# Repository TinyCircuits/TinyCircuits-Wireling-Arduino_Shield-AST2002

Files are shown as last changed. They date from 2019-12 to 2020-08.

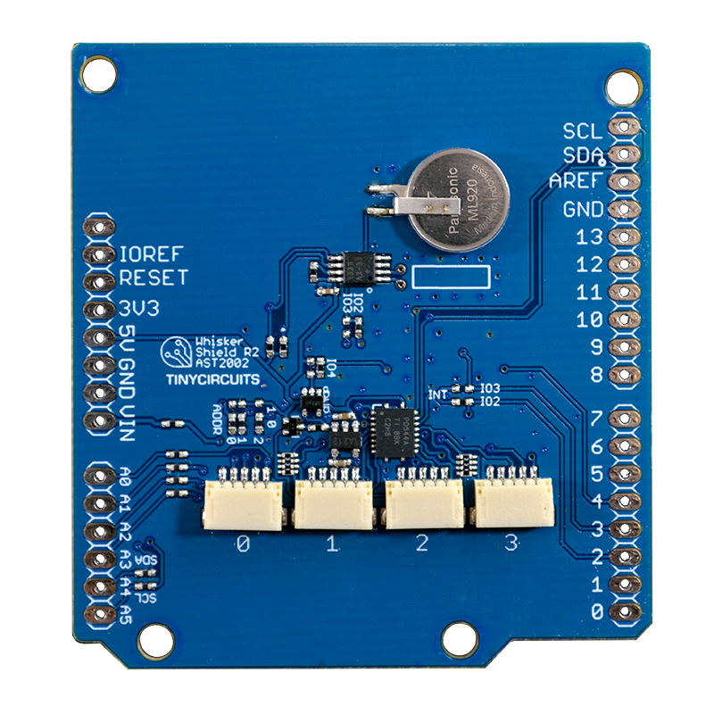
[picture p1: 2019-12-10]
images/AST2002-Tutorial-Image-01.png

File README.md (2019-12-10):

# TinyCircuits Wireling Arduino Shield AST2002
# AST2002 Rev2

The design files are located under design_files/ for the TinyCircuits AST2002 Rev 2 PCB. This is a Standard Arduino Shield that allows Standard Arduino users to connect up to 4 Wirelings to their Arduino projects.

Format is in Cadsoft Eagle format - Eagle version 6.2 was used for the original design.

For more infomation on this, check out the product page at TinyCircuits.com

# License:

Design by TinyCircuits.
All design files are released under the Creative Commons Attribution Share-Alike 3.0 License, see the following link for details: http://creativecommons.org/licenses/by-sa/3.0

All text above must be included in any redistribution or derived design

This project uses designs and concepts developed as part of the Arduino project and the LilyPad project.  The TinyCircuits design files themselves (schematics, PCB and libraries) are not directly derived from these works' design files and have been created new, however the concepts and basic architecture behind the TinyDuino and TinyLily products are derived and we thank the hard work of the organizations below for their contributions to open-source hardware:
  
Original Arduino Uno Design by Team Arduino

LilyPad Arduino Design by Leah Buechley and Sparkfun Electronics

Please support the open-source hardware community

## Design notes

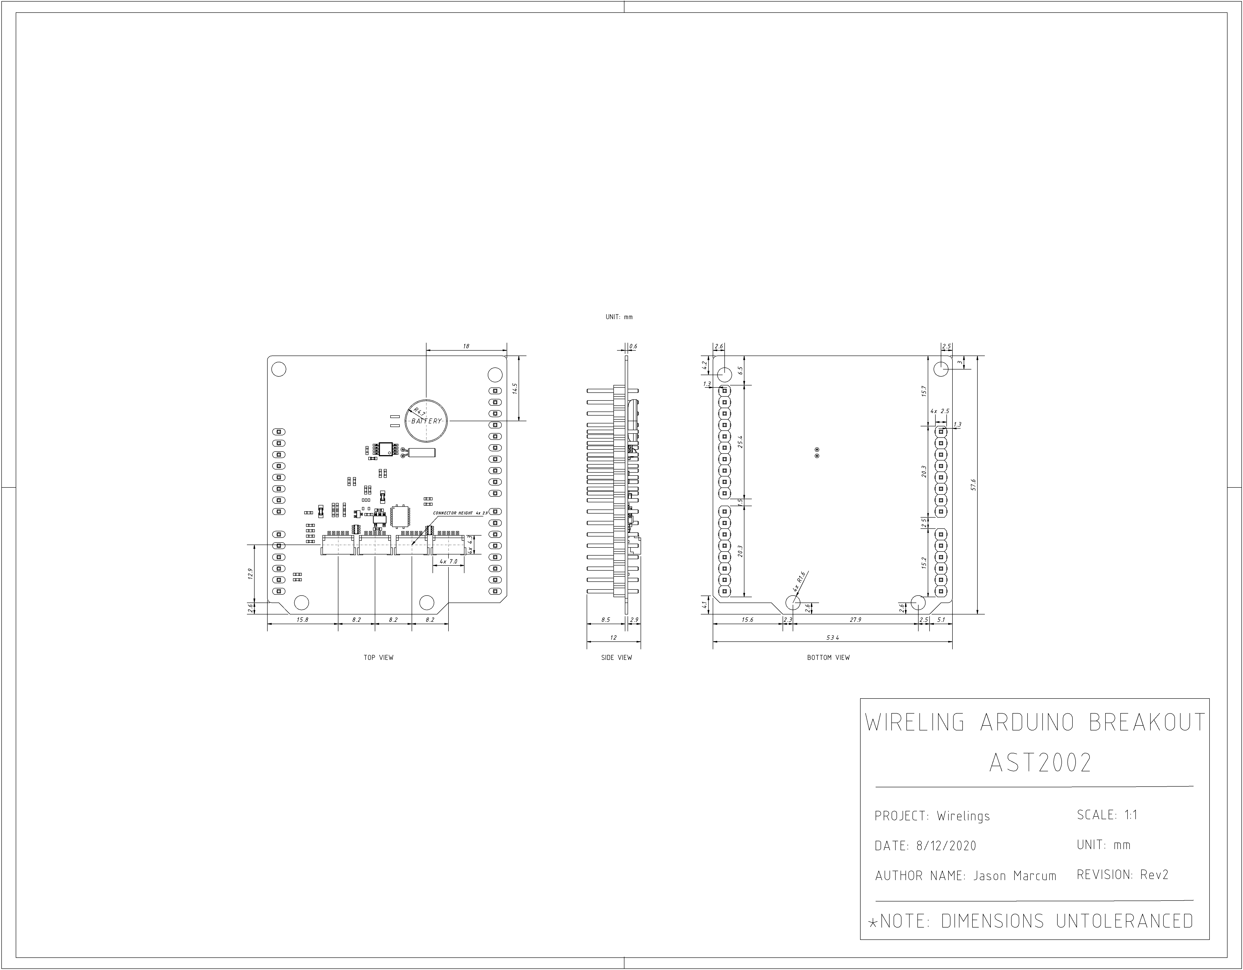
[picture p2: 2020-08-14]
cad/Wireling_ARDUINO_AST2002_REV2-DETAILED_DRAWING-PNG.png

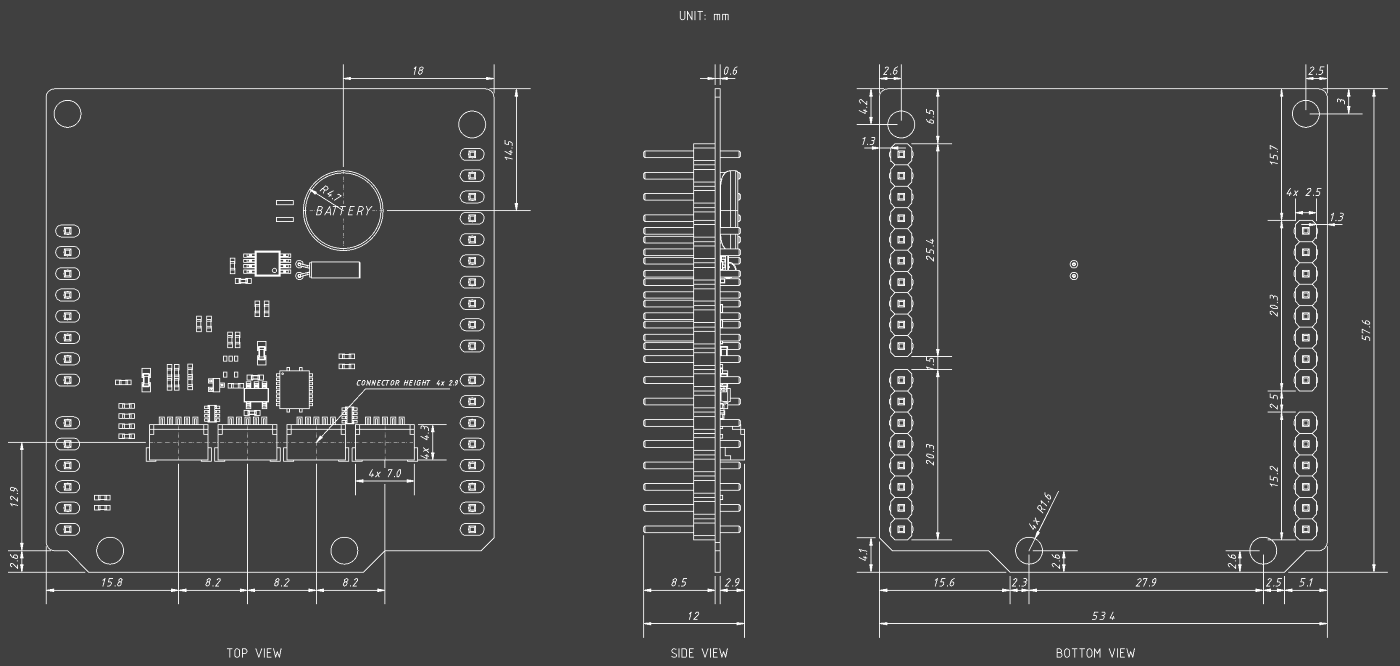
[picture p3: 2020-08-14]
cad/Wireling_ARDUINO_AST2002_REV2-DETAILED_DRAWING_COMPACT-PNG.png

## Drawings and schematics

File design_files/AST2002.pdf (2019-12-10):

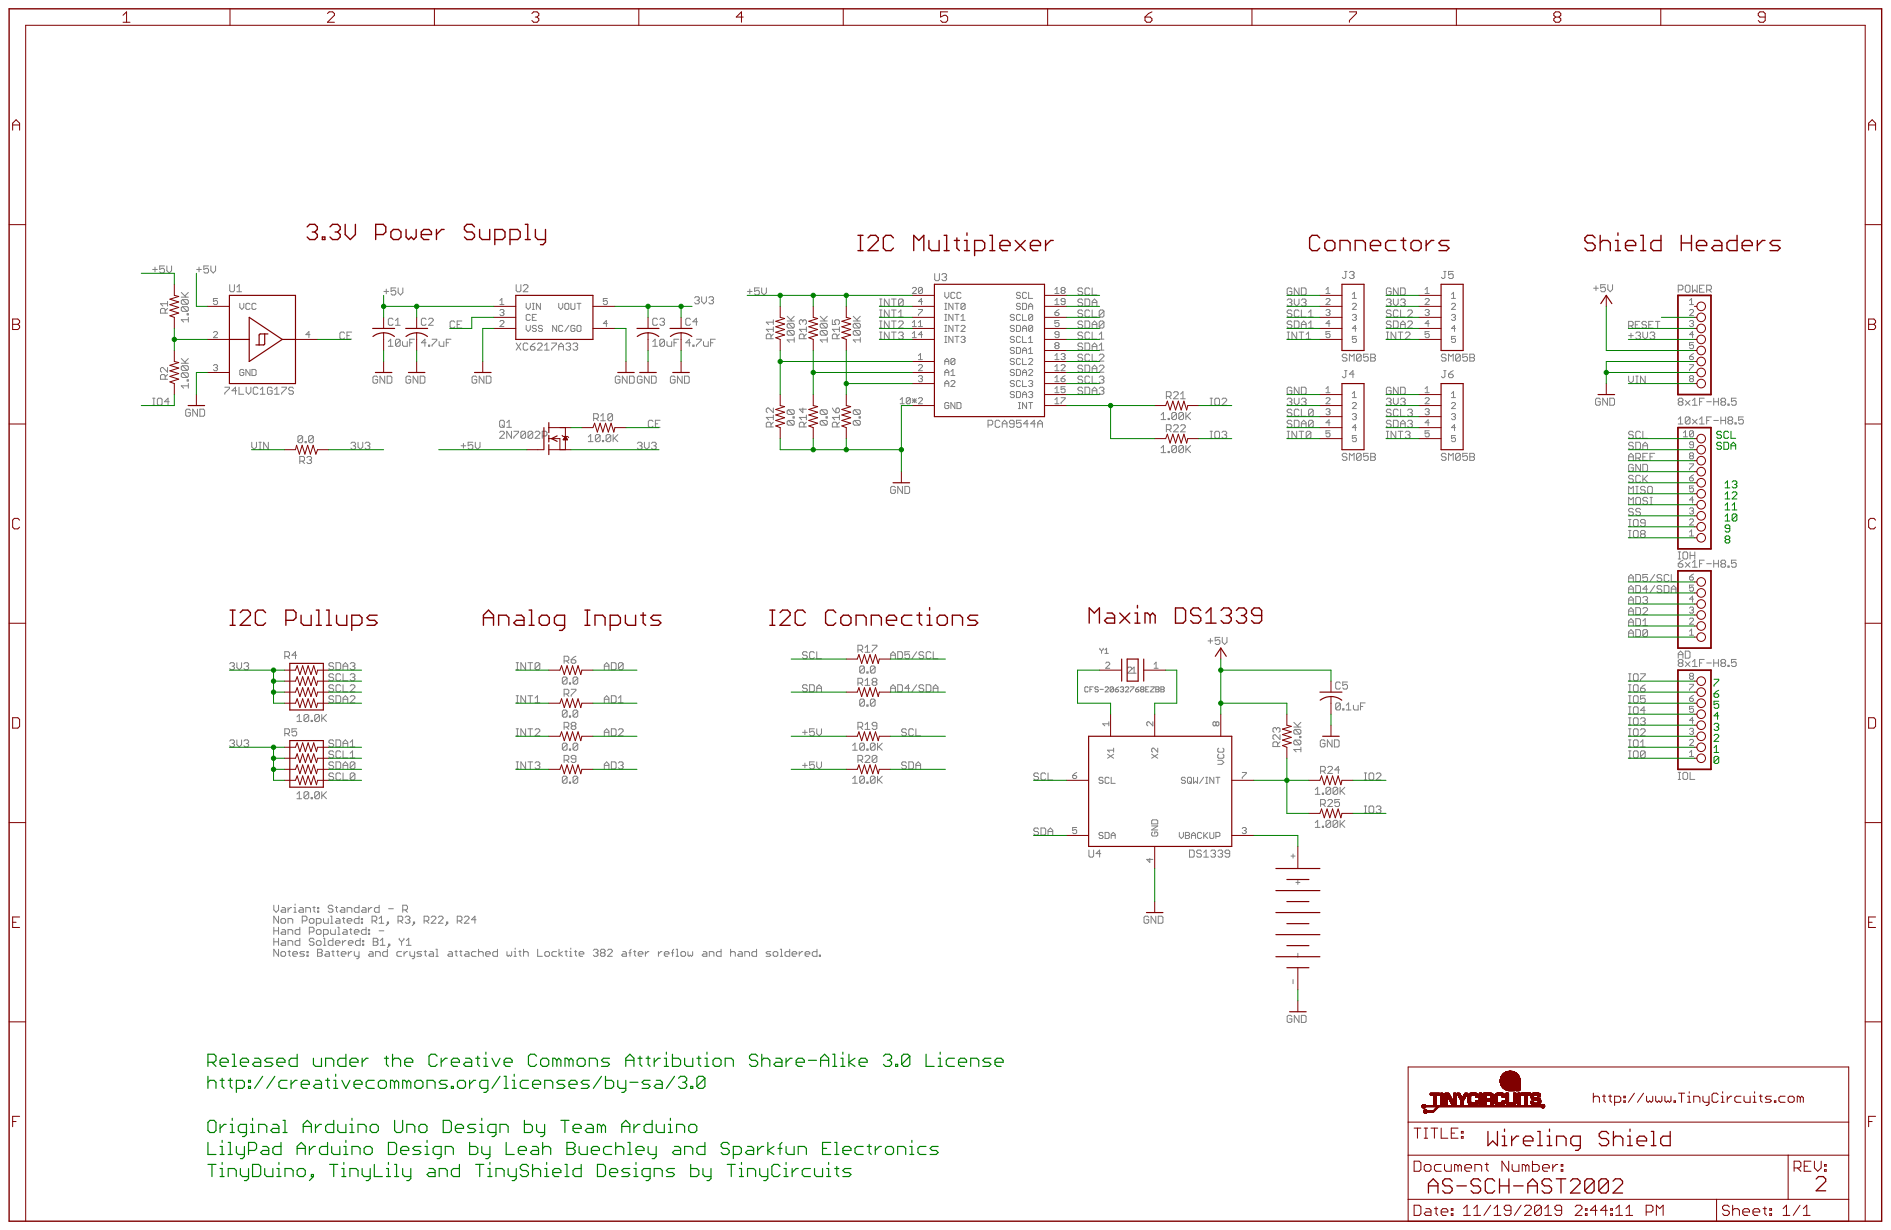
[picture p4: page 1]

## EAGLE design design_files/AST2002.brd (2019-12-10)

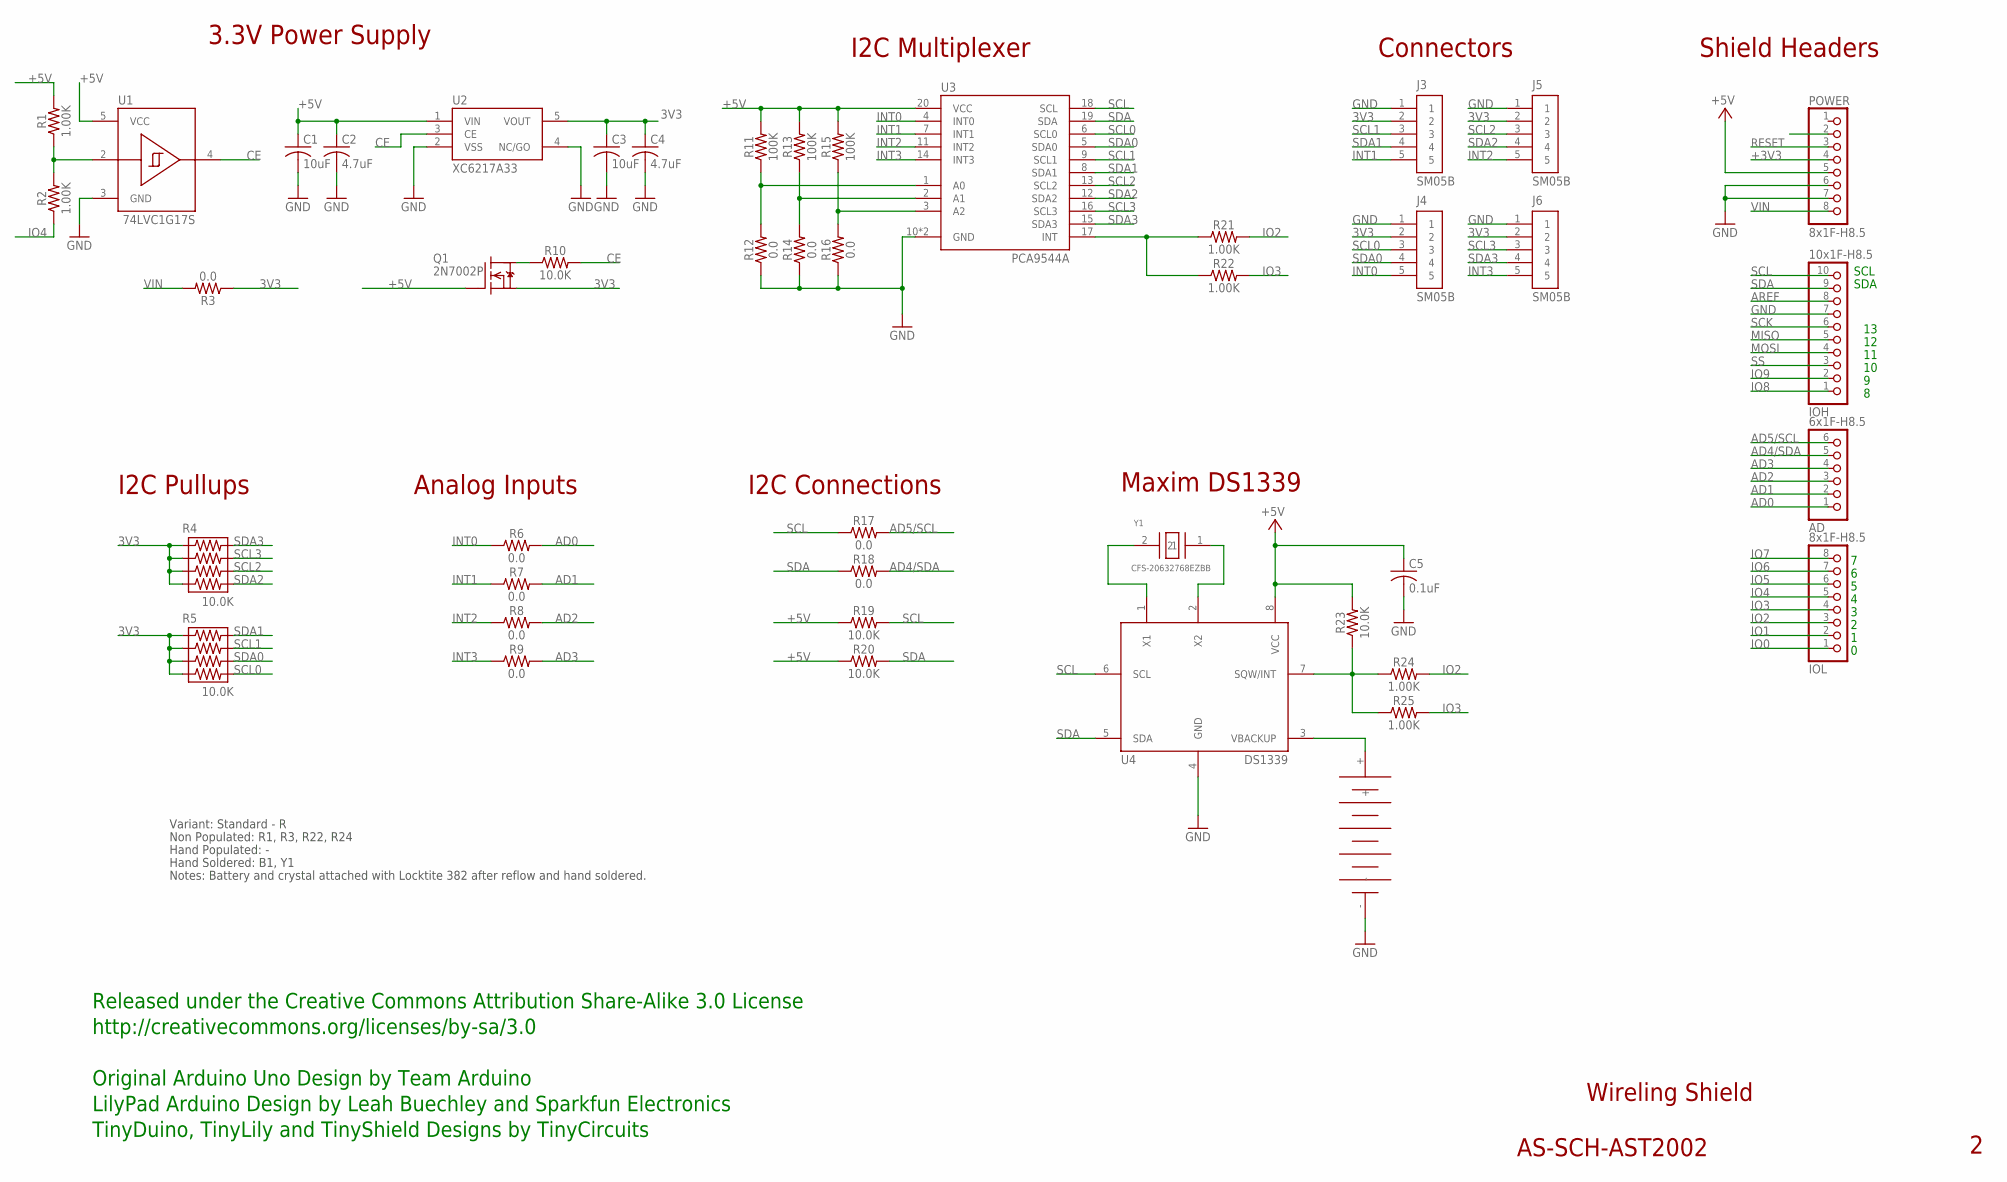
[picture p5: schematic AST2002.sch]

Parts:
AD: 6x1F-H8.5; 1X06
B1: ML-920S/DN
C1: 10uF; C0603; PARTNO AS-ITM-00002
C2, C4: 4.7uF; C0402; PARTNO AS-ITM-00242
C3: 10uF; C0603
C5: 0.1uF; C0402
IOH: 10x1F-H8.5; 1X10
IOL: 8x1F-H8.5; 1X08
J3, J4, J5, J6: SM05B; JST_SH_5X1
POWER: 8x1F-H8.5; 1X08
Q1: 2N7002P; SOT-416; PARTNO AS-ITM-00110
R1, R2, R24, R25: 1.00K; 0402; PARTNO AS-ITM-00003
R3, R12, R14, R16: 0.0; 0402; PARTNO AS-ITM-00076
R4, R5: 10.0K; 0402RPACK; PARTNO AS-ITM-00520
R6, R7, R8, R9, R17, R18: 0.0; 0402
R10, R23: 10.0K; 0402; PARTNO AS-ITM-00032
R11, R13, R15: 100K; 0402; PARTNO AS-ITM-00004
R19, R20: 10.0K; 0402
R21, R22: 1.00K; 0402
U1: 74LVC1G17S; SOT-353
U2: XC6217A33; SOT-25; PARTNO AS-ITM-00249
U3: PCA9544A; VQFN-20_4.5X3.5
U4: DS1339; 8-USOP
Y1: CFS-20632768EZBB; CRYSTAL_1.9MM_TH

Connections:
3V3: C3.1, C4.1, J3.2, J4.2, J5.2, J6.2, Q1.2 (S), R3.1, R4.1, R4.3, R4.5, R4.7, R5.1, R5.3, R5.5, R5.7, U2.5 (VOUT)
+3V3: POWER.4
+5V: C1.1, C2.1, C5.1, POWER.5, Q1.1 (G), R1.2, R11.2, R13.2, R15.2, R19.1, R20.1, R23.2, U1.5 (VCC), U2.1 (VIN), U3.20 (VCC), U4.8 (VCC)
AD0: AD.1, R6.2
AD1: AD.2, R7.2
AD2: AD.3, R8.2
AD3: AD.4, R9.2
AD4/SDA: AD.5, R18.2
AD5/SCL: AD.6, R17.2
AREF: IOH.8
CE: R10.2, U1.4 (Y), U2.3 (CE)
GND: B1.-, C1.2, C2.2, C3.2, C4.2, C5.2, IOH.7, J3.1, J4.1, J5.1, J6.1, POWER.6, POWER.7, R12.1, R14.1, R16.1, U1.3 (GND), U2.2 (VSS), U2.4 (NC/GO), U3.10 (GND), U3.PAD (GND), U4.4 (GND)
INT0: J4.5, R6.1, U3.4 (INT0)
INT1: J3.5, R7.1, U3.7 (INT1)
INT2: J5.5, R8.1, U3.11 (INT2)
INT3: J6.5, R9.1, U3.14 (INT3)
IO0: IOL.1
IO1: IOL.2
IO2: IOL.3, R21.2, R24.2
IO3: IOL.4, R22.2, R25.2
IO4: IOL.5, R2.1
IO5: IOL.6
IO6: IOL.7
IO7: IOL.8
IO8: IOH.1
IO9: IOH.2
MISO: IOH.5
MOSI: IOH.4
unnamed: Q1.3 (D), R10.1
unnamed: R11.1, R12.2, U3.1 (A0)
unnamed: R15.1, R16.2, U3.3 (A2)
unnamed: R21.1, R22.1, U3.17 (INT)
unnamed: R13.1, R14.2, U3.2 (A1)
unnamed: R23.1, R24.1, R25.1, U4.7 (SQW/INT)
unnamed: B1.+, U4.3 (VBACKUP)
unnamed: U4.1 (X1), Y1.2 (1)
unnamed: U4.2 (X2), Y1.1 (2)
unnamed: R1.1, R2.2, U1.2 (A)
RESET: POWER.3
SCK: IOH.6
SCL: IOH.10, R17.1, R19.2, U3.18 (SCL), U4.6 (SCL)
SCL0: J4.3, R5.8, U3.6 (SCL0)
SCL1: J3.3, R5.4, U3.9 (SCL1)
SCL2: J5.3, R4.6, U3.13 (SCL2)
SCL3: J6.3, R4.4, U3.16 (SCL3)
SDA: IOH.9, R18.1, R20.2, U3.19 (SDA), U4.5 (SDA)
SDA0: J4.4, R5.6, U3.5 (SDA0)
SDA1: J3.4, R5.2, U3.8 (SDA1)
SDA2: J5.4, R4.8, U3.12 (SDA2)
SDA3: J6.4, R4.2, U3.15 (SDA3)
SS: IOH.3
VIN: POWER.8, R3.2

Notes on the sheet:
Shield Headers
Wireling Shield
AS-SCH-AST2002
Released under the Creative Commons Attribution Share-Alike 3.0 License
http://creativecommons.org/licenses/by-sa/3.0
LilyPad Arduino Design by Leah Buechley and Sparkfun Electronics
TinyDuino, TinyLily and TinyShield Designs by TinyCircuits
Original Arduino Uno Design by Team Arduino
3.3V Power Supply
I2C Multiplexer
Connectors
Analog Inputs
I2C Pullups
Non Populated: R1, R3, R22, R24
Variant: Standard - R
SDA
SCL
Maxim DS1339
Hand Populated: -
Hand Soldered: B1, Y1
Notes: Battery and crystal attached with Locktite 382 after reflow and hand soldered.
I2C Connections

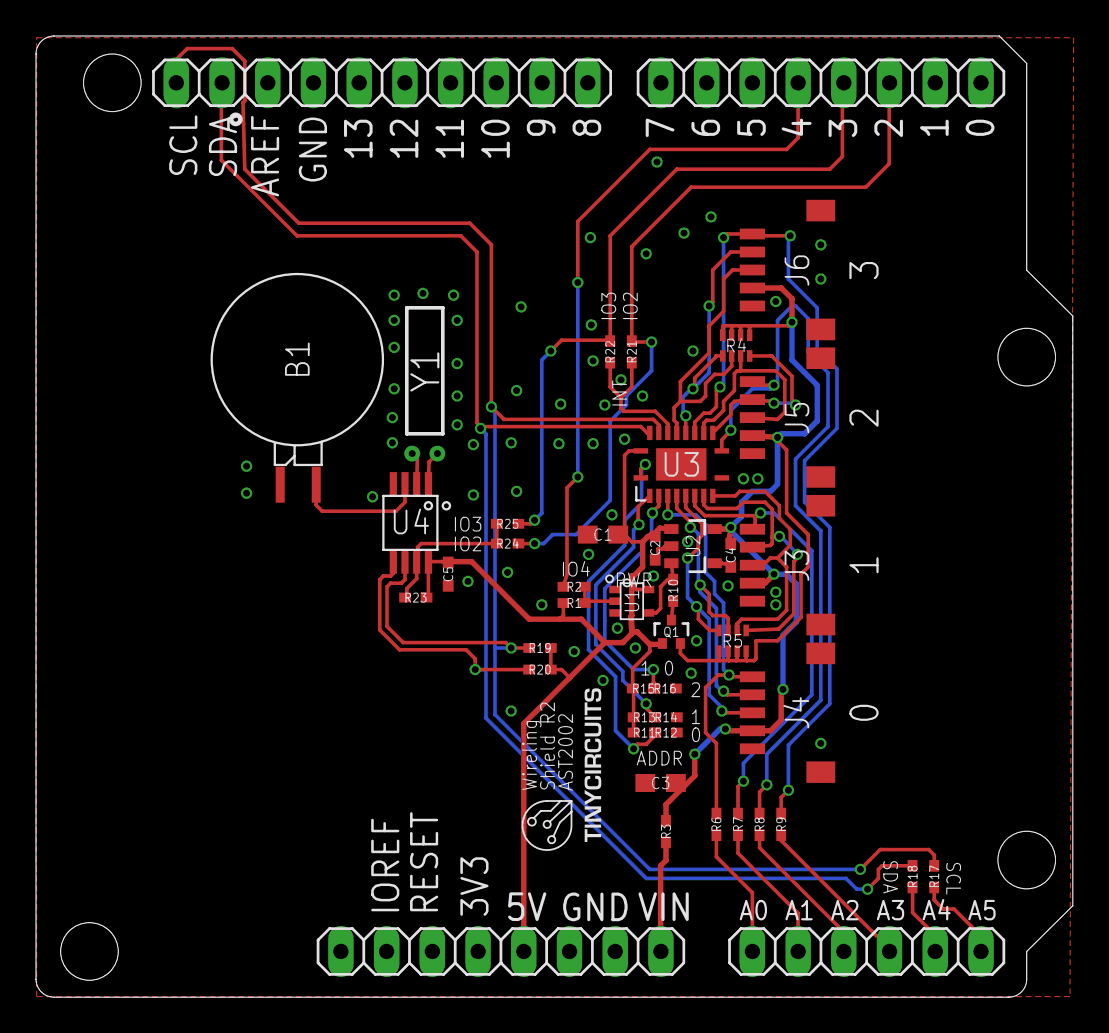
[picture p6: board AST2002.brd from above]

Board: 2 copper layers, 57.6 x 53.4 mm, 46 parts (0 on the bottom side), 38 nets.

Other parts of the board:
U$1: DOCFIELD-TINYCIRCUITS-PCB

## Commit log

2019-12-10 first init
    [AST2002.brd, AST2002.sch]
2020-08-14 Add CAD data
